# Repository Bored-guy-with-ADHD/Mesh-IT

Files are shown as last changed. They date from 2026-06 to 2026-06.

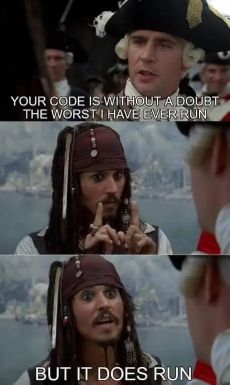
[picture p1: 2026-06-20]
Software/Mesh-IT, Meshtastic Source Code/firmware-2.7.15.567b8ea/src/graphics/niche/InkHUD/docs/disclaimer.jpg

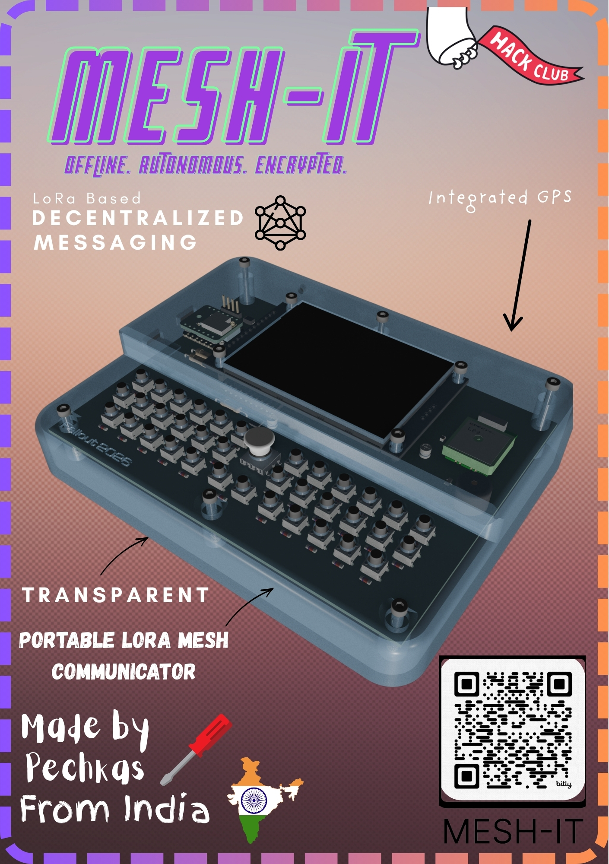
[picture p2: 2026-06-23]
Assests/fallout_zine.jpg

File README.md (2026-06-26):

# Mesh-IT
Mesh-IT is a handheld LoRa mesh messaging device designed for offline communication. It is built around the Seeed Studio Xiao ESP32-S3 and the Wio-Sx1262 LoRa Module
The Device Has a 2.8-inch colour TFT display, a 5x7 keyboard matrix, joystick navigation, GPS support, and a custom transparent 3D-printed enclosure
# Why I made it 
I wanted to build something that feels like a real product, not something held by tape and hopes.
I made this to solve a critical problem: communication in rural areas
I chose LoRa for a reason, it has excellent range and is low power, and it's cheap, costing around 60$ for 1 unit of Mesh-IT
# Project Images
## Zine 
fallout_zine

## PCB/schematic








## Enclosure render


# onshape links
assembly link
(https://cad.onshape.com/documents/168fda0a8f16824cccb64ee6/w/7f9acbf670b84dd77c93c7b4/e/36fa08238f3aeb1c026e0e22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)

original workspace link (https://cad.onshape.com/documents/f08658297db9b835bf0cb4c0/w/964f5e8aa7a9c980c94da242/e/11eb6b47f6372a176f6b115a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)

STEP FILES
(https://cad.onshape.com/documents/0d6a45b3dd53ce5ed637c55e/w/97f38c8d6e16f4a215b96871/e/82edf1f08dcd1788016565fc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)
# Repository structure
This repo is divided into 3 main folders
1. Assets: Contains the zine page, PCB photo, and BOM Link
2. Hardware: contains the KiCad files, Gerber files, and enclosure files
3. Software: contains the Meshtastic source code used for the project
# BOM
|Name of the modules and components |quantity |Column1|Cost in INR |Cost in USD|Vender |payment gateway  |Link to the Components |Notes |
|---|---|---|---|---|---|---|---|---|
|Seed Studio XIAO ESP32S3 & Wio-SX1262 Kit |1 unit | |1250Rs |13.36 USD  |RoboCraze |Cashfree Payments|https://robocraze.com/products/xiao-esp32s3-wio-sx1262-kit-for-meshtastic-lora | |
|NOVA 105050 3000mAh 3.7V Micro LiPo Battery pack with Protection |1 unit | |448Rs |4.79 USD |Robu.in |Razorpay |https://robu.in/product/nova-105050-3000mah-3-7v-micro-lipo-battery-pack/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 | |
|2.8-inch SPI Screen Module TFT Interface 240 x 320 |1 unit | |502Rs |5.36 USD |Robu.in |Razorpay |https://robu.in/product/2-8-inch-spi-screen-module-tft-interface-240-x-320-without-touch/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 | |
|MCP23017 IO Expander |1 units | |295X2 =590Rs |6.30 USD |Sharvi electronics|Razorpay |https://sharvielectronics.com/product/mcp23017-io-expander-serial-module-with-i2c-serial-interface/ |Footprint made, cross verification to be done|
|6x6x8mm Tactile Push Button Switch |35 units | |1.42X35=49.7Rs |0.53 USD |Robu.in |Razorpay |https://robu.in/product/6x6x8mm-tactile-push-button-switch-pack-of-20/ | |
|header pins male and female |approx 3-4 strips| |150~ |1.62 USD |amazon |amazon |https://amzn.in/d/0hcru4TC | |
|1N4148 SMD Diodes |35 units | |2.31x35=80.85Rs|0.86 USD |Robu.in |Razorpay |https://robu.in/product/1n4148-surface-mount-zener-diode-pack-of-30/ | |
|0.1uf 50V Electrolytic Capacitor 4�7 mm |2 units | |1.8x2=3.6Rs |0.038 USD  |Sharvi electronics|Razorpay |https://sharvielectronics.com/product/0-1uf-50v-electrolytic-capacitor-4x7-mm/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 | |
|4.7k? Resistors |2 units | |1.78x4=7.12Rs  |0.076 USD  |Robu.in |Razorpay |https://robu.in/product/4-7k-ohm-1w-metal-film-resistor-pack-of-40/ | |
|5V buzzer |1 unit | |5Rs |0.053 USD  |Robu.in |Razorpay |https://robu.in/product/1-month-warranty-1248/ | |
|Type-C USB 5V 3.1A Boost Step-Up Power Module Lithium Battery Charging Protection Board LED Display|1 unit | |199Rs |2.13 USD |RoboticsDNA |Razorpay |https://roboticsdna.in/product/type-c-usb-5v-3-1a-boost-step-up-power-module-lithium-battery-charging-protection-board-led-display-usb-for-diy-charger-no-weld/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{adgroup}&device=c&campaign={campaign}&adgroup={adgroup}&keyword=&matchtype=&gad_source=1&gad_campaignid=23684419086&gbraid=0AAAAAC-xzeHGeoXQ55OAHaQCIb7zfF5Bw&gclid=Cj0KCQjwy_fOBhC6ARIsAHKFB78in6-iXOiUay3XAbAS1s5LUVEdgtFZzN9HRiBrgJL9wrLbAssALQcaAuQGEALw_wcB\| |
|K1-1504SA-03-Hroparts-SMD,10x10mm Multi-Directional Switches ROHS |1 unit | |Rs53 |0.56 USD |Robu.in |Razorpay |https://robu.in/product/k1-1504sa-03-hroparts-smd10x10mm-multi-directional-switches-rohs/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 |Wil need to check pinout with Multimeter |
|868MHZ 3dbi antenna for lora |1 Unit | |172Rs |1.84 USD |Sharvi electronics|Razorpay |https://sharvielectronics.com/product/868mhz-lora-gateway-antenna-3dbi-gain-with-sma-male-connector/ | |
|15CM SMA Female to IPEX1 Connector Cable Thread 13mm RG1.13 |1 unit | |123Rs |1.32USD |Robu.in |Razorpay |https://robu.in/product/15cm-sma-female-to-ipex1-connector-cable-thread-13/ | |
|10k Ohm 0.25W Metal Film Resistor |1 unit | |0.35Rs |0.37 USD |Robu.in |Razorpay |https://robu.in/product/10k-ohm-0-25w-metal-film-resistor-pack-of-100/ | |
|L89HA GPS |1 unit | |808RS |8.57 USD |Robocraze |U pay |https://robocraze.com/products/l89ha-multi-gnss-breakout-module-for-gps-irnss-glonass-beidou-galileo-qzss-7semi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 | |
|MAX17048 |1 unit | |339RS |3.6 USD |RoboCraze |Cashfree Payments|https://robocraze.com/products/max17048-li-poly-li-ion-fuel-gauge-breakout-board-mini-7semi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 | |
|4 Pin JST-XH Single Side Female Polarized Header with 300mm Wire -2.54mm pitch |1 unit | |12Rs |0.13 USD |Sharvi electronics|Razorpay |https://sharvielectronics.com/product/4-pin-jst-xh-female-polarized-header-wire/ | |
|4 Pin JST-XH Male Straight 2515 Connector 2.54mm Pitch |1 unut | |3.25 |0.34 USD |Sharvi electronics|Razorpay |https://sharvielectronics.com/product/4-pin-jst-xh-male-straight-2515-connector-2-54mm-pitch/ | |
|1k Ohm 0.25W,1/4W Metal Film Resistor |1 unit | |0.90RS |0.94 USD |Robu.in |Razorpay |https://robu.in/product/1k-ohm-0-25w-metal-film-resistor-pack-of-100/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 | |
|Sub-Miniature Toggle Switch (Pack of 5) |1 Unit | |66RS |0.69 USD |RoboCraze |U pay |https://robocraze.com/products/sub-miniature-toggle-switchpack-of-5 | |
|SS14 skotty diode |1 Unit | |16Rs |0.17 USD |Robu.in |Razorpay |https://robu.in/product/ss14-e3-5at-vishay-ss14-e3-5at-diode-schottky-1a-40v-do-214ac-2/ | |
|SS8050 |1 Unit | |6Rs |0.7 USD |Robu.in |Razorpay |https://robu.in/product/ss8050range200-300-jiangsu-changjing-electronics-technology-co-ltd-25v-1w-200800ma1v-1-5a-npn-to-92-3-bipolar-bjt-rohs/ | |
|Transparent Soft Silicone Switch Cap For 6X6mm Switches |35 Units | |160Rs |1.69 USD |Sharvi electronics|Razorpay |https://sharvielectronics.com/product/transparent-soft-silicone-switch-cap-for-6x6mm-switches/ | |
|Black Rubber Cap for 10x10x9mm Five Way Switch |1 Unit | |18Rs |0.20 USD |RoboticsDNA |Razorpay |https://roboticsdna.in/product/black-rubber-cap-for-10x10x9mm-five-way-switch/ | |
|PCB |1unit | |640 Rs |6.80 USD |JLCPCB |N/A |N/A | |
|TOTAL | | |5740 RS |60.85 USD  |=== | | | |

#   How to assemble it
1. First, take the display and align it with the cutout for the display and screw it in
2. Then put the heat inserts in the backplate
3. Then insert the switch on the right side of the enclosure
4. Then wire the switch between the battery input and the charging module, the input
5. Then glue the Charging module onto the little platform near Xiao
6. Then solder the charging module's power path to the 5V pin and GND, situated on the top left
7. and solder the bat-in
8. Then cover the battery with Kapton tape, and stick it on the back of the PCB in the designated Silkscreen area using double-sided tape(Preferred 3KG one) 
9. Then align the PCB carefully and screw everything in(The case was engineered so that the battrey wont come lose, i didnt make an enclosure to avoid squiching the battrey)
# Flashing custom firmware
To flash the firmware, you will need to open the Meshtastic web flasher (https://flasher.meshtastic.org/)
Then, in the select target section, select Seed Studio Xiao, then select your firmware file and hit flash
# Timeline
Schematic and research took me around 25 hours
and making the PCB took around 45 hours
and 3d enclosure took around 30 hours of trial and error

# Current STATUS
1. PCB design is complete
2. Enclosure is complete
3. Gerber files are included
4. Zine page is complete
5. Physical build and firmware testing are still pending
# Credits
Special thanks to the Meshtastic team for open-source software
# licence
This project is open-source and released under the MIT license

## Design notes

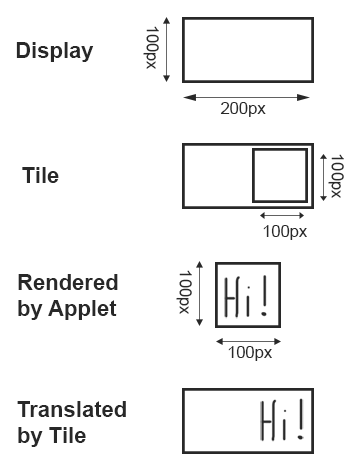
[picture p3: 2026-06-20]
Software/Mesh-IT, Meshtastic Source Code/firmware-2.7.15.567b8ea/src/graphics/niche/InkHUD/docs/tile_translation.png

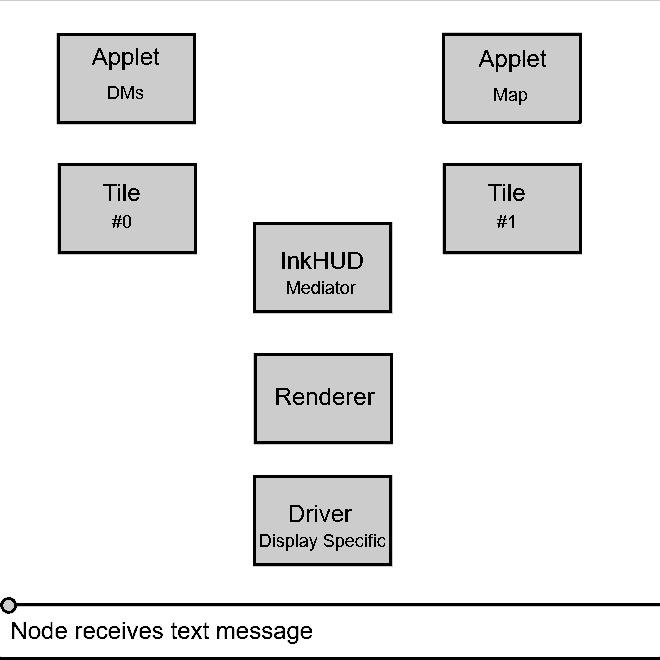
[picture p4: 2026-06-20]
Software/Mesh-IT, Meshtastic Source Code/firmware-2.7.15.567b8ea/src/graphics/niche/InkHUD/docs/rendering.gif

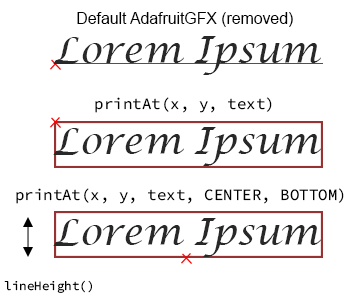
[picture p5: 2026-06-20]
Software/Mesh-IT, Meshtastic Source Code/firmware-2.7.15.567b8ea/src/graphics/niche/InkHUD/docs/appletfont.png

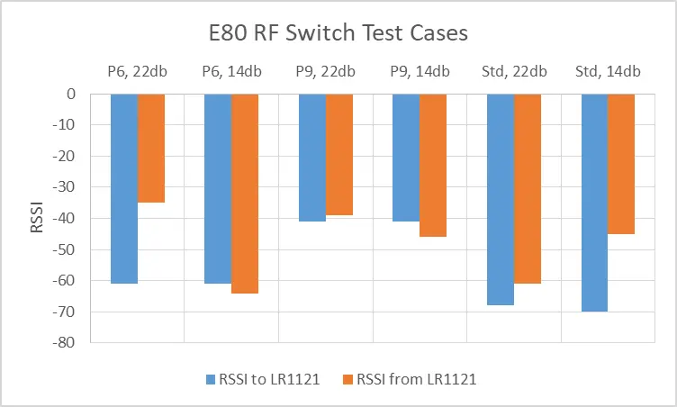
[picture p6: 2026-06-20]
Software/Mesh-IT, Meshtastic Source Code/firmware-2.7.15.567b8ea/variants/nrf52840/diy/nrf52_promicro_diy_tcxo/E80_RSSI_per_case.webp

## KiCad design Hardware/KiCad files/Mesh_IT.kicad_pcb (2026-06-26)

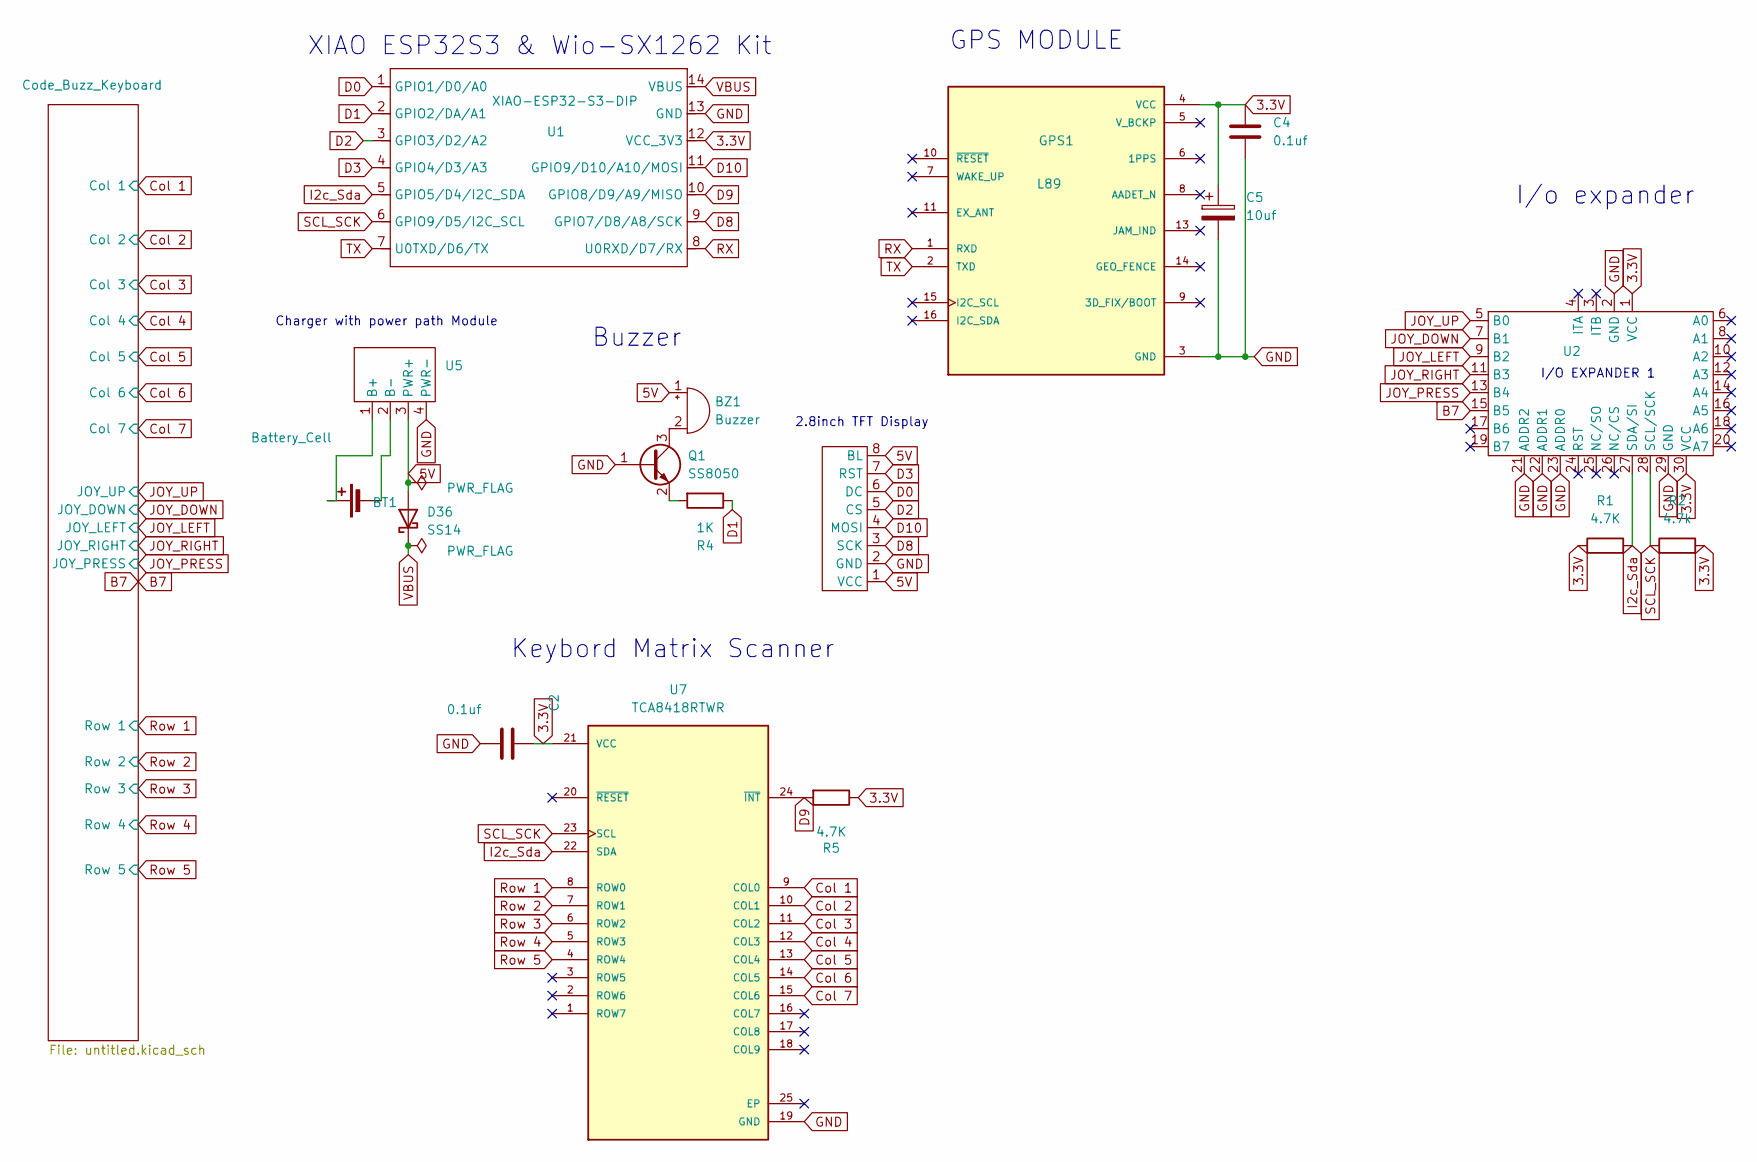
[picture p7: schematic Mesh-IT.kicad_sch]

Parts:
BT1: Battery_Cell; 3000Mah battrey uh
BZ1: Buzzer; Buzzer_12x9.5RM7.6
C2, C4: 0.1uf; CP_Radial_D4.0mm_P2.00mm
C5: 10uf; C_0805_2012Metric
D36: SS14; D_SMA
GPS1: L89; XCVR_L89; PARTREV 1.1
Q1: SS8050; SOT-23
R1, R5: 4.7K; R_Axial_DIN0309_L9.0mm_D3.2mm_P15.24mm_Horizontal
R2: 4.7k; R_Axial_DIN0309_L9.0mm_D3.2mm_P15.24mm_Horizontal
R4: 1K; R_Axial_DIN0204_L3.6mm_D1.6mm_P7.62mm_Horizontal
U1: XIAO-ESP32-S3-DIP; XIAO-ESP32S3-DIP
U2: io expander
U5: PinHeader_1x04_P2.54mm_Vertical
U7: TCA8418RTWR; QFN50P400X400X80-25N; PARTREV G
u3: 2.8 inch tft display

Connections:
3.3V: C2.2, C4.1, C5.1, GPS1.4 (VCC), R1.1, R2.2, R5.1, U1.12 (VCC_3V3), U2.1 (VCC), U2.30 (VCC), U7.21 (VCC)
5V: BZ1.1 (+), D36.2 (A), U5.3 (PWR+), u3.1 (VCC), u3.8 (BL)
B7: U2.15 (B5); also elsewhere on the board
Col 1: U7.9 (COL0); also elsewhere on the board
Col 2: U7.10 (COL1); also elsewhere on the board
Col 3: U7.11 (COL2); also elsewhere on the board
Col 4: U7.12 (COL3); also elsewhere on the board
Col 5: U7.13 (COL4); also elsewhere on the board
Col 6: U7.14 (COL5); also elsewhere on the board
Col 7: U7.15 (COL6); also elsewhere on the board
D0: U1.1 (GPIO1/D0/A0), u3.6 (DC)
D1: R4.1, U1.2 (GPIO2/DA/A1)
D2: U1.3 (GPIO3/D2/A2), u3.5 (CS)
D3: U1.4 (GPIO4/D3/A3), u3.7 (RST)
D8: U1.9 (GPIO7/D8/A8/SCK), u3.3 (SCK)
D9: R5.2, U1.10 (GPIO8/D9/A9/MISO), U7.24 (~INT)
D10: U1.11 (GPIO9/D10/A10/MOSI), u3.4 (MOSI)
GND: C2.1, C4.2, C5.2, GPS1.3 (GND), GPS1.12 (GND), Q1.1 (B), U1.13 (GND), U2.2 (GND), U2.21 (ADDR2), U2.22 (ADDR1), U2.23 (ADDR0), U2.29 (GND), U5.4 (PWR-), U7.19 (GND), u3.2 (GND)
I2c_Sda: R1.2, U1.5 (GPIO5/D4/I2C_SDA), U2.27 (SDA/SI), U7.22 (SDA)
JOY_DOWN: U2.7 (B1); also elsewhere on the board
JOY_LEFT: U2.9 (B2); also elsewhere on the board
JOY_PRESS: U2.13 (B4); also elsewhere on the board
JOY_RIGHT: U2.11 (B3); also elsewhere on the board
JOY_UP: U2.5 (B0); also elsewhere on the board
unnamed: BT1.1 (+), U5.1 (B+)
unnamed: BT1.2 (-), U5.2 (B-)
unnamed: BZ1.2 (-), Q1.3 (C)
unnamed: Q1.2 (E), R4.2
RX: GPS1.1 (RXD), U1.8 (U0RXD/D7/RX)
Row 1: U7.8 (ROW0); also elsewhere on the board
Row 2: U7.7 (ROW1); also elsewhere on the board
Row 3: U7.6 (ROW2); also elsewhere on the board
Row 4: U7.5 (ROW3); also elsewhere on the board
Row 5: U7.4 (ROW4); also elsewhere on the board
SCL_SCK: R2.1, U1.6 (GPIO9/D5/I2C_SCL), U2.28 (SCL/SCK), U7.23 (SCL)
TX: GPS1.2 (TXD), U1.7 (U0TXD/D6/TX)
VBUS: D36.1 (K), U1.14 (VBUS)

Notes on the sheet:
I/O EXPANDER 1
Charger with power path Module
I/o expander
XIAO ESP32S3 & Wio-SX1262 Kit
GPS MODULE
2.8inch TFT Display
Buzzer
Keybord Matrix Scanner

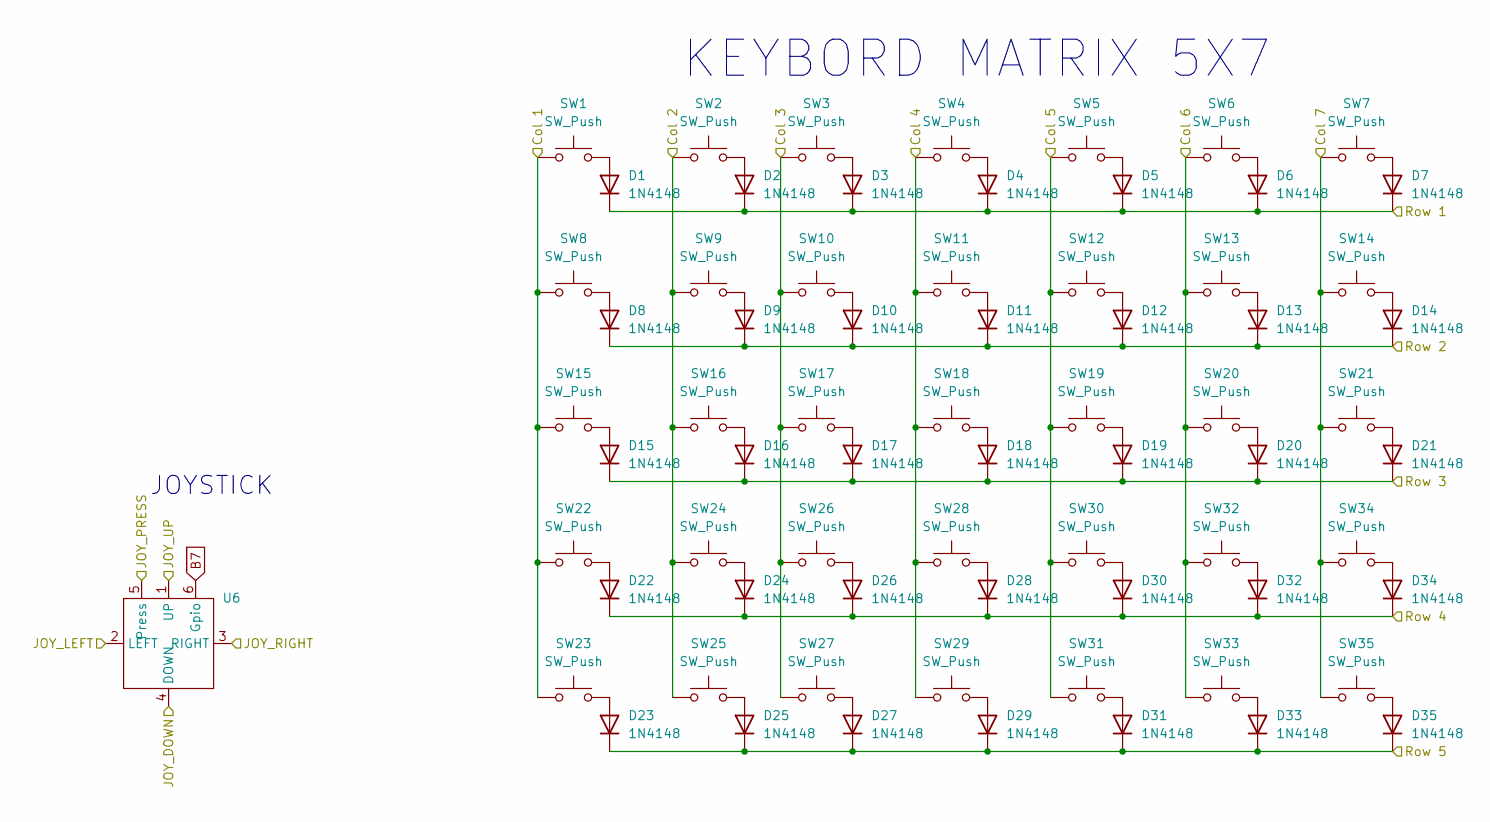
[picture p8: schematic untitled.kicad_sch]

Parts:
D1, D2, D3, D4, D5, D6, D7, D8, D9, D10, D11, D12, D13, D14, D15, D16, D17, D18, D19, D20, D21, D22, D23, D24, D25, D26, D27, D28, D29, D30, D31, D32, D33, D34, D35: 1N4148; D_MiniMELF
SW1, SW2, SW3, SW4, SW5, SW6, SW7, SW8, SW9, SW10, SW11, SW12, SW13, SW14, SW15, SW16, SW17, SW18, SW19, SW20, SW21, SW22, SW23, SW24, SW25, SW26, SW27, SW28, SW29, SW30, SW31, SW32, SW33, SW34, SW35: SW_Push; SW_PUSH_6mm_H8mm
U6: New Joystick

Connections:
B7: U6.6 (Gpio); also elsewhere on the board
Col 1: SW1.1, SW8.1, SW15.1, SW22.1, SW23.1; also elsewhere on the board
Col 2: SW2.1, SW9.1, SW16.1, SW24.1, SW25.1; also elsewhere on the board
Col 3: SW3.1, SW10.1, SW17.1, SW26.1, SW27.1; also elsewhere on the board
Col 4: SW4.1, SW11.1, SW18.1, SW28.1, SW29.1; also elsewhere on the board
Col 5: SW5.1, SW12.1, SW19.1, SW30.1, SW31.1; also elsewhere on the board
Col 6: SW6.1, SW13.1, SW20.1, SW32.1, SW33.1; also elsewhere on the board
Col 7: SW7.1, SW14.1, SW21.1, SW34.1, SW35.1; also elsewhere on the board
JOY_DOWN: U6.4 (DOWN); also elsewhere on the board
JOY_LEFT: U6.2 (LEFT); also elsewhere on the board
JOY_PRESS: U6.5 (Press); also elsewhere on the board
JOY_RIGHT: U6.3 (RIGHT); also elsewhere on the board
JOY_UP: U6.1 (UP); also elsewhere on the board
unnamed: D1.2 (A), SW1.2
unnamed: D2.2 (A), SW2.2
unnamed: D3.2 (A), SW3.2
unnamed: D4.2 (A), SW4.2
unnamed: D5.2 (A), SW5.2
unnamed: D6.2 (A), SW6.2
unnamed: D7.2 (A), SW7.2
unnamed: D8.2 (A), SW8.2
unnamed: D9.2 (A), SW9.2
unnamed: D10.2 (A), SW10.2
unnamed: D11.2 (A), SW11.2
unnamed: D12.2 (A), SW12.2
unnamed: D13.2 (A), SW13.2
unnamed: D14.2 (A), SW14.2
unnamed: D15.2 (A), SW15.2
unnamed: D16.2 (A), SW16.2
unnamed: D17.2 (A), SW17.2
unnamed: D18.2 (A), SW18.2
unnamed: D19.2 (A), SW19.2
unnamed: D20.2 (A), SW20.2
unnamed: D21.2 (A), SW21.2
unnamed: D22.2 (A), SW22.2
unnamed: D23.2 (A), SW23.2
unnamed: D24.2 (A), SW24.2
unnamed 51: D25.2 (A), SW25.2; also elsewhere on the board
unnamed: D26.2 (A), SW26.2
unnamed: D27.2 (A), SW27.2
unnamed: D28.2 (A), SW28.2
unnamed: D29.2 (A), SW29.2
unnamed: D30.2 (A), SW30.2
unnamed: D31.2 (A), SW31.2
unnamed: D32.2 (A), SW32.2
unnamed: D33.2 (A), SW33.2
unnamed: D34.2 (A), SW34.2
unnamed: D35.2 (A), SW35.2
Row 1: D1.1 (K), D2.1 (K), D3.1 (K), D4.1 (K), D5.1 (K), D6.1 (K), D7.1 (K); also elsewhere on the board
Row 2: D8.1 (K), D9.1 (K), D10.1 (K), D11.1 (K), D12.1 (K), D13.1 (K), D14.1 (K); also elsewhere on the board
Row 3: D15.1 (K), D16.1 (K), D17.1 (K), D18.1 (K), D19.1 (K), D20.1 (K), D21.1 (K); also elsewhere on the board
Row 4: D22.1 (K), D24.1 (K), D26.1 (K), D28.1 (K), D30.1 (K), D32.1 (K), D34.1 (K); also elsewhere on the board
Row 5: D23.1 (K), D25.1 (K), D27.1 (K), D29.1 (K), D31.1 (K), D33.1 (K), D35.1 (K); also elsewhere on the board

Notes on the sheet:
JOYSTICK
KEYBORD MATRIX 5X7

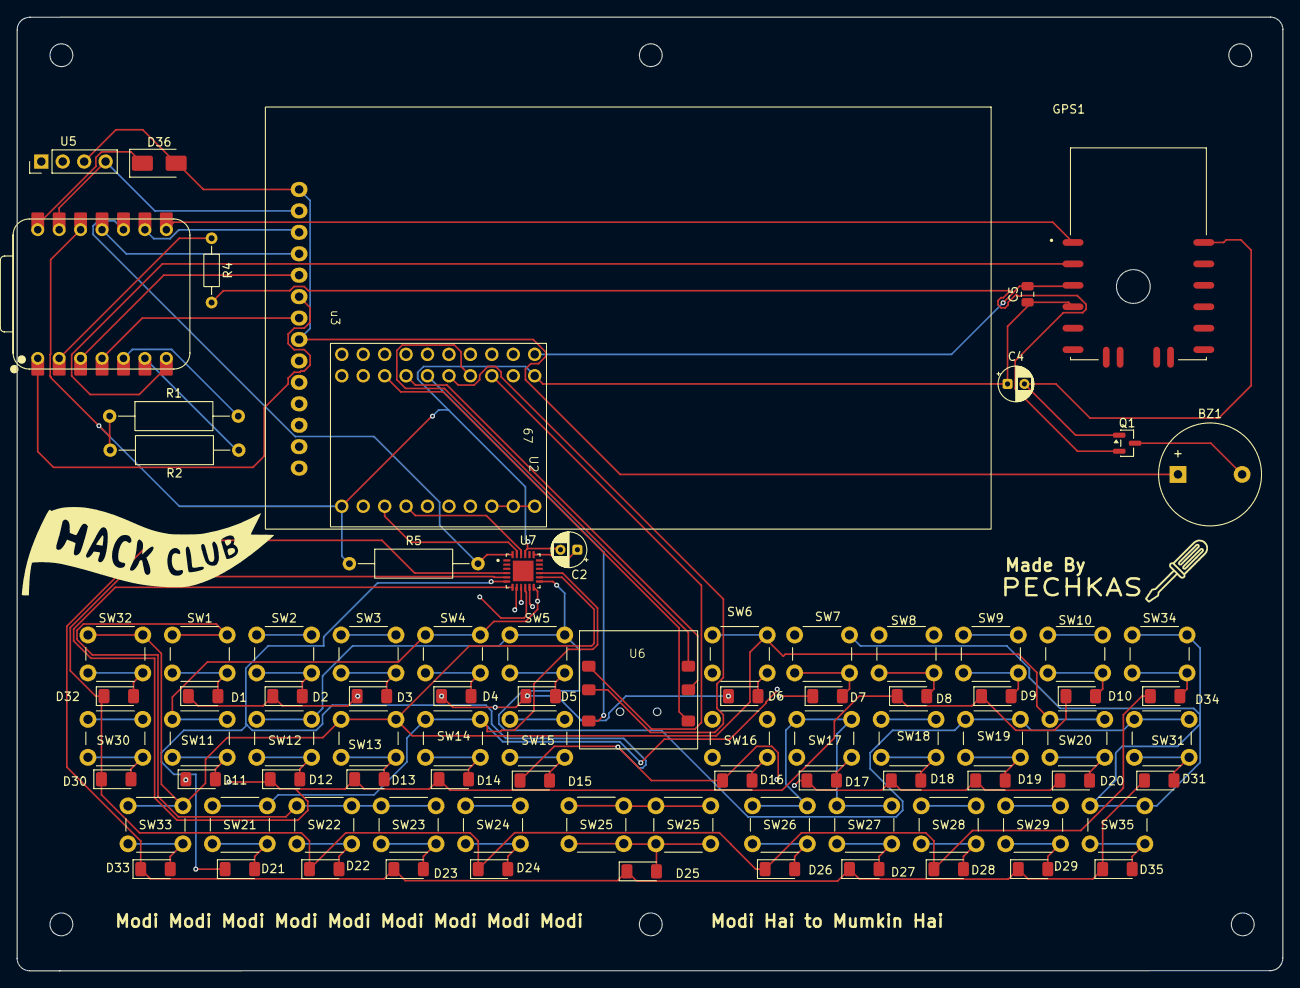
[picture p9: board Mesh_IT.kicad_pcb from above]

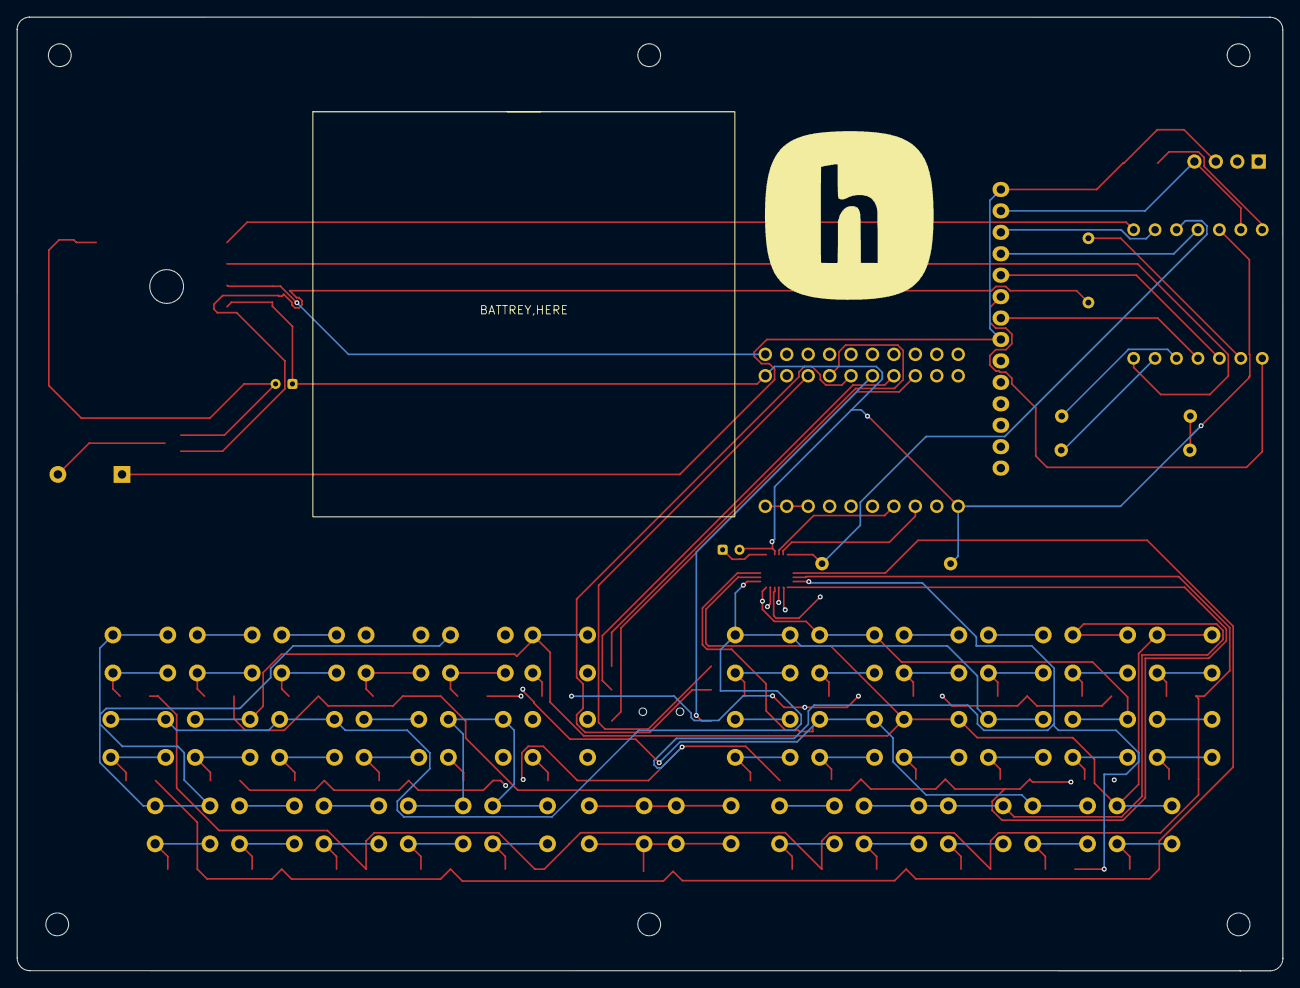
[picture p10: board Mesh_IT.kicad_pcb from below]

Board: 4 copper layers, 150.0 x 113.0 mm, 91 parts (2 on the bottom side), 70 nets.

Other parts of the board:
., .#2: LOGO
BATTREY,HERE: Battery_Cell; 3000Mah battrey uh
SW25#2: SW_Push; SW_PUSH_6mm_H8mm

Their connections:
Col 2: SW25#2.1; also elsewhere on the board
unnamed 51: SW25#2.2; also elsewhere on the board

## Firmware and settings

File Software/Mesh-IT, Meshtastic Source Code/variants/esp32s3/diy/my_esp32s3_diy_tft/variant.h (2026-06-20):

// variant.h
// Board: XIAO ESP32-S3 + Wio-SX1262 Kit
// Firmware: Meshtastic v2.7.15

// GPS
#define HAS_GPS 1
#define GPS_RX_PIN  44
#define GPS_TX_PIN  43

// ST7789 TFT display
#define ST7789_SDA    10
#define ST7789_SCK    8
#define ST7789_CS     3
#define ST7789_RS     1
#define ST7789_RESET  4
#define ST7789_BL     5
#define ST7789_MISO  -1
#define ST7789_BUSY  -1

#define ST7789_SPI_HOST     SPI2_HOST
#define TFT_BL              5
#define SPI_FREQUENCY       40000000
#define SPI_READ_FREQUENCY  16000000
#define TFT_HEIGHT          320
#define TFT_WIDTH           240
#define TFT_OFFSET_X        0
#define TFT_OFFSET_Y        0
#define TFT_OFFSET_ROTATION 0
#define SCREEN_ROTATE
#define SCREEN_TRANSITION_FRAMERATE 5

// SX1262 LoRa
#define USE_SX1262

#undef  LORA_SCK
#define LORA_SCK   8
#undef  LORA_MISO
#define LORA_MISO  9
#undef  LORA_MOSI
#define LORA_MOSI  10
#undef  LORA_CS
#define LORA_CS    7

#define LORA_RESET  6
#define LORA_DIO1   2
#define LORA_DIO2   3

#define SX126X_CS       LORA_CS
#define SX126X_DIO1     LORA_DIO1
#define SX126X_BUSY     LORA_DIO2
#define SX126X_RESET    LORA_RESET
#define SX126X_DIO2_AS_RF_SWITCH
#define SX126X_DIO3_TCXO_VOLTAGE 1.8

// I2C
#define I2C_SDA  5
#define I2C_SCL  6

// Keyboard
#define INPUTBROKER_MATRIX_TYPE 1
#define CANNED_MESSAGE_MODULE_ENABLE 1

// Neopixel
#define HAS_NEOPIXEL
#define NEOPIXEL_COUNT 1
#define NEOPIXEL_DATA  38
#define NEOPIXEL_TYPE  (NEO_GRB + NEO_KHZ800)

// User button
#define BUTTON_PIN 0
#define BUTTON_NEED_PULLUP

// Buzzer
#define PIN_BUZZER 2

// Power / battery
#define BATTERY_PIN    1
#define ADC_CHANNEL    ADC1_GPIO1_CHANNEL
#define ADC_MULTIPLIER 2.0

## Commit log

2026-06-12 Rename project from CodeBuzz-Relay to Mesh-IT
    Updated project name and description for clarity.
2026-06-20 Add files via upload
    GERBERS
2026-06-20 Revise README with comprehensive project details
    Expanded the README to include detailed features, repository information, enclosure design, build instructions, credits, and licensing.
2026-06-20 Revise README.md for Mesh-IT project details
    Updated README.md to provide a comprehensive overview of the Mesh-IT project, including features, assembly instructions, and credits.
2026-06-20 organize repo files
    Organize repo files
    [.isort.cfg, codeBuzz copy.kicad_pcb, codeBuzz.kicad_sch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]
2026-06-20 Enhance README with project details and instructions
    Expanded README.md to provide detailed project information, images, assembly instructions, and current status.
2026-06-20 Create Bom for CodeBuzz.csv
    [Bom for CodeBuzz.csv]
2026-06-20 Add BOM section with components and costs
    Added a Bill of Materials (BOM) section with detailed components and their costs.
2026-06-20 Rename codeBuzz copy.kicad_pcb to Mesh-IT.kicad_pcb
    [Mesh-IT.kicad_pcb]
2026-06-20 Add Mesh-IT.kicad_pro file
2026-06-20 something changed
    [Mesh-IT-V1.step]
2026-06-20 Uploading final files
    [Mesh-IT.kicad_pcb, Mesh-IT.kicad_sch]
2026-06-20 Refactor variant.h for improved readability
    Updated comments and pin definitions for clarity and organization.
2026-06-23 Re uploading fixed files
    [Mesh-IT-Enclosure_V1.step, Mesh-IT-V1.step, Mesh-IT.kicad_pcb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]
2026-06-23 Update README with new images for Zine and PCB
    Added a new image to the Zine section and updated the PCB section with an image.
2026-06-23 Changes based on review
    [Mesh-IT-Enclosure_V1.step]
2026-06-26 Revise BOM formatting and add assembly instructions
    Updated the BOM section with corrected formatting, quantities, and links for components. Added a section on assembly instructions.
2026-06-26 changer based on reviewers feedback
    [BOM.csv, Mesh_IT.kicad_pcb]
2026-06-26 Add Onshape assembly link for Mesh-IT enclosure
2026-06-26 Update PCB section with schematic images
2026-06-26 Update README with Onshape links
    Added Onshape links for assembly, original workspace, and STEP files.
